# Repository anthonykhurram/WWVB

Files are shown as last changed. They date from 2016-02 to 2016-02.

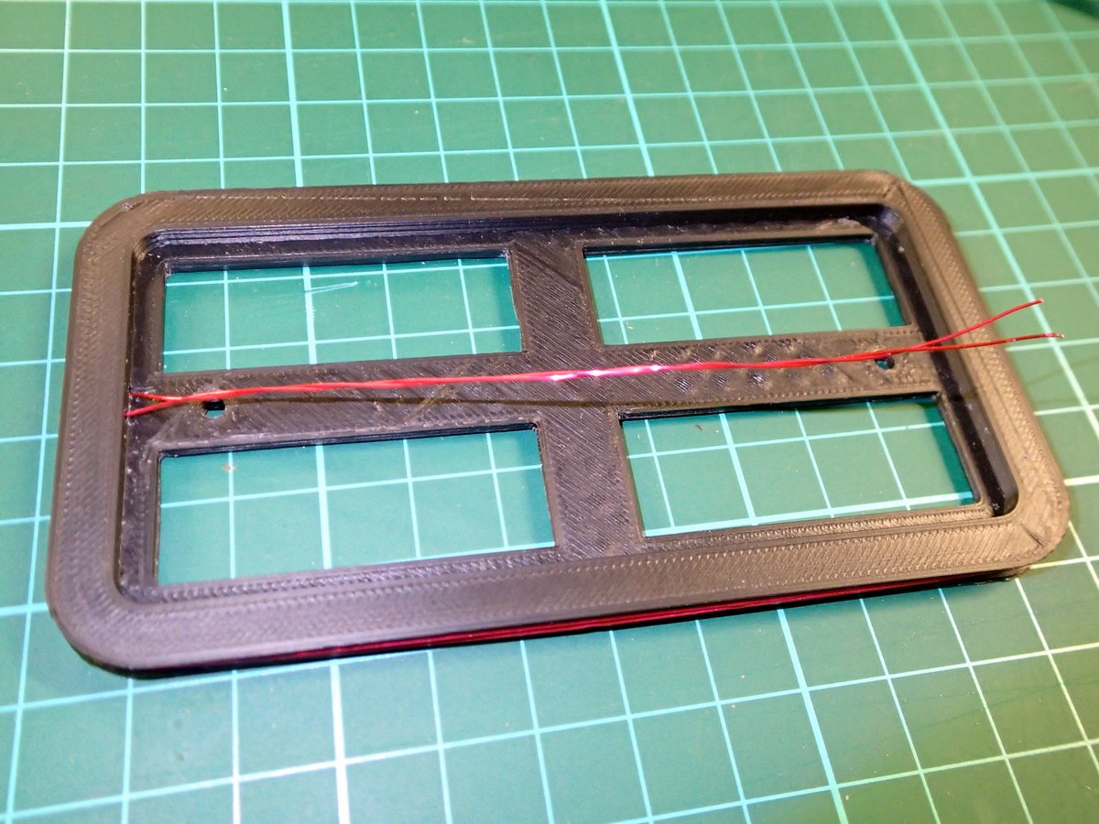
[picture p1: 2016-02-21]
Images & schematic/Coil1.JPG

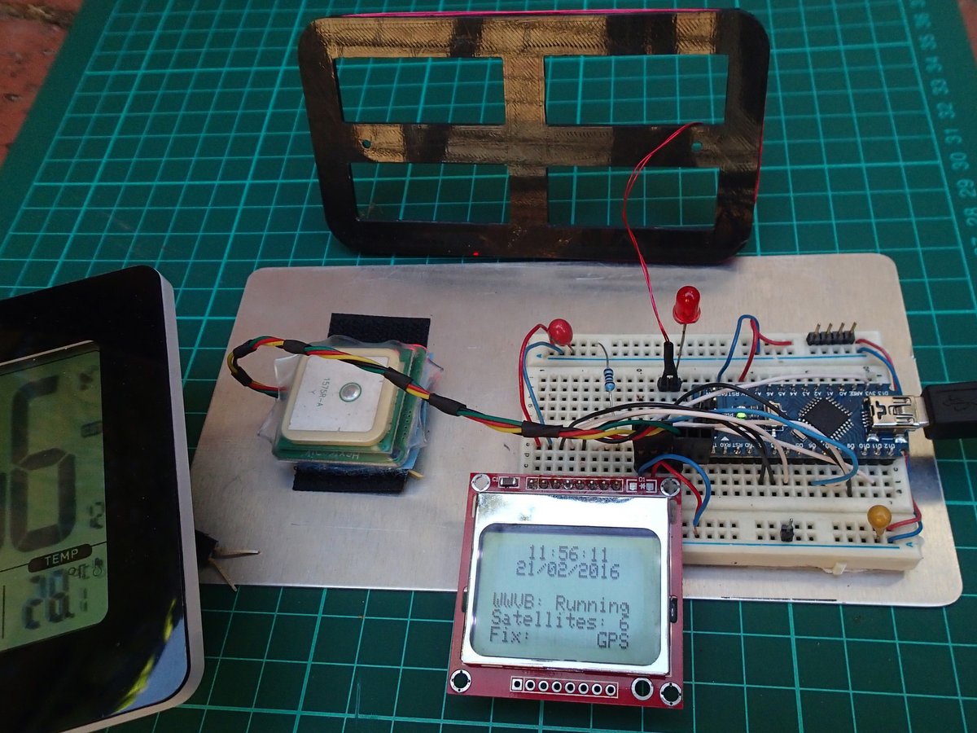
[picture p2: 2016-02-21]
Images & schematic/Breadboard1.JPG

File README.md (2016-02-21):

## Arduino Nano with Nokia LCD 60Khz WWVB Transmitter for setting radio controlled 'Atomic Clocks' like Oregon Scientific, Baldr, Casio Wave Ceptor, Citizen etc. 
An Arduino based WWVB transmitter project. The point of this is to get sub second time accuracy on radio controlled clocks in countries that don't support it.

## Tested successfully on a Baldr brand WWVB clock so far.
https://www.youtube.com/watch?v=lA-yf535rdY :Demo video of a radio controlled clock setting its time from the project.

## Not tested successfully on other devices as yet.

## Basic system info
The Nano uses the serial UTC time strings from the GPS module to synchronize a low power WWVB time signal transmission (range approx 1 meter).
The arduino code converts the UTC time to local time for the Nokia LCD, and also converts UTC to different offset for the WWVB generation.
The reason for that is the WWVB clock may not be built to be used in the time zone you are in (like Australia).
So a clock made for the USA, Japan or Europe can be set to display correct for any other time zone automatically (I have a Baldr desk clock made for the USA, and use it in Australia). 
The Nokia LCD shows current local time as read from the serial GPS module. The lower half of the LCD shows the WWVB and GPS statuses.
The WWVB time information will be output for 6 minutes before the Nano will re-sync with the GPS time and repeat. 
Radio Controlled clocks periodically try to receive a WWVB signal during the night and update the time. This project should enable clocks and watches within a meter or so to do this also.
The anticipated usage would be to have this on a bedside table and your radio controlled wrist watch and alarm clock will update each night to sub second accurate time (just like it would in countries like the USA, Japan, Europe, China).

Compile time options are:
GPS module type
Local time zone offset
WWVB time zone offset
Nokia LCD contrast value

* Author/s: [Mark Cooke](https://www.github.com/micooke), [Martin Sniedze](https://www.github.com/mr-sneezy)

## Requirements
* [TimeDateTools.h](https://github.com/micooke/ATtinyGPS/TimeDateTools.h)
* [ATtinyGPS.h](https://github.com/micooke/ATtinyGPS/ATtinyGPS.h) : for setting time based off a serial GPS
* [wwvb.h](https://github.com/micooke/WWVB/wwvb.h) : WWVB library
* Arduino Nano or clone
* Serial GPS module like a uBlox 6M or MTK 3329 that works with 5V supply.
* Nokia 5110 display module  - https://www.sparkfun.com/products/10168

##Options
* 3D printed coil bobbin (coil holder)  - http://www.thingiverse.com/thing:1358090

## About
http://www.nist.gov/pml/div688/grp40/wwvb.cfm

WWVB: 60kHz carrier, Amplitude modulated to Vp -17dB for signal low

## TODO:
* Draw up a schematic. If you can't wait it's actually fairly easy to use the pin diagram in the INO. 
* The GPS is direct connected to the Nano, the LCD also. Use a 1K to 500 ohm for the LCD back light limiting. The coil is driven directly through a limiting resistor or through an LED (the real current limiting is by the AVRs internal I/O limiter).
* Also to do, add LCD backlight control via the Nano. Use two digital pins via diodes and two resistors to have 'day & night' brightness settings, set by real time.

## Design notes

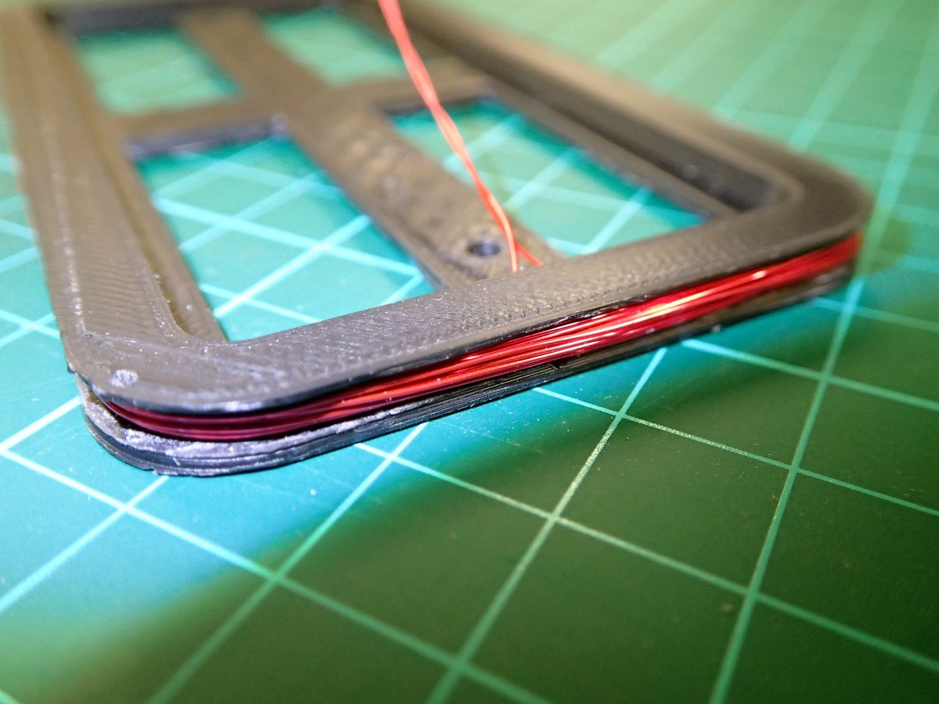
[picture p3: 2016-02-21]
Images & schematic/Coil2.JPG

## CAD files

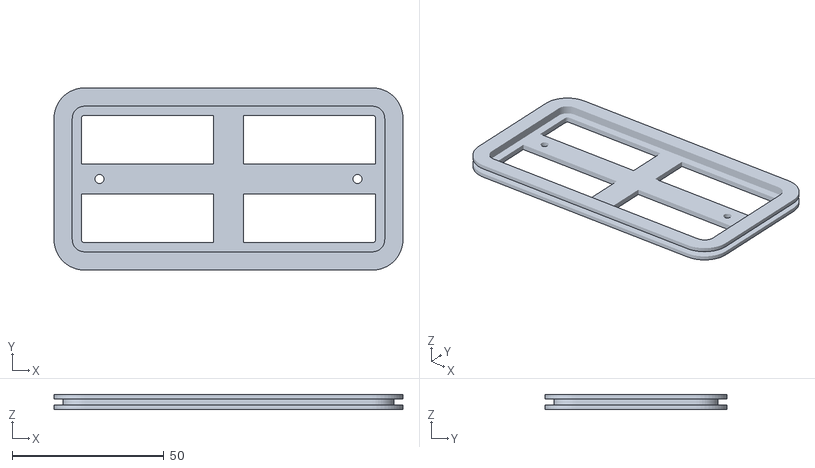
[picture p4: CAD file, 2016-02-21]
Images & schematic/WWVB Coil 1.stl
115.0 x 60.0 x 5.00

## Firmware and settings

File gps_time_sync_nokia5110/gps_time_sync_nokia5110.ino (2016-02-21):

#include <Arduino.h>
//ATtiny85 - Not enough pins & compile size too large
//
//Arduino Nano
//              +----+=====+----+
//              |    | USB |    |
// LCD CLK <= 13| D13+-----+D12 |12 MISO
//              |3V3        D11~|11 => LCD Din
//              |Vref       D10~|10 SS
//            14| A0/D14     D9~|9 => WWVB ANTENNA
//            15| A1/D15     D8 |8
//            16| A2/D16     D7 |7 <= GPS Tx (Software Serial)
//            17| A3/D17     D6~|6 => GPS Rx (Software Serial)
//        SDA 18| A4/D18     D5~|5
//        SCL 19| A5/D19     D4 |4 => LCD RST
//            20| A6         D3~|3 => LCD CE/CS (Chip Enable)
//            21| A7         D2 |2 => LCD DC (Data/Command Select)
//              | 5V        GND |
//              | RST       RST |
//              | GND       TX1 |0
//              | Vin       RX1 |1
//              |  5V MOSI GND  |
//              |   [ ][ ][ ]   |
//              |   [*][ ][ ]   |
//              | MISO SCK RST  |
//              +---------------+
//
//Arduino Micro
//              +--------+=====+---------+
//              |        | USB |         |
//        SCK 13| D13    +-----+     D12 |12 MISO
//              |3V3                 D11~|11 => LCD Din
//              |Vref                D10~|10 SS
// LCD DC  <= 14| A0/D14              D9~|9 => WWVB ANTENNA
// LCD CE  <= 15| A1/D15              D8 |8
// LCD RST <= 16| A2/D16              D7 |7 <= GPS Tx (Software Serial)
//            17| A3/D17              D6~|6 => GPS Rx (Software Serial)
//        SDA 18| A4/D18              D5~|5
//        SCL 19| A5/D19              D4 |4
//            20| A6                  D3~|3 INT1
//            21| A7                  D2 |2 INT0
//              | 5V                 GND |
//              | RST                RST |
//              | GND                TX1 |0
//              | Vin                RX1 |1
//              |MISO MISO[*][ ]VCC    SS|
//              |SCK   SCK[ ][ ]MOSI MOSI|
//              |      RST[ ][ ]GND      |
//              +------------------------+
//
//Sparkfun Pro Micro
//                             +----+=====+----+
//                             |[J1]| USB |    |
//                            1| TXO+-----+RAW |
//                            0| RXI       GND |
//                             | GND       RST |
//                             | GND       VCC |
//                        SDA 2| D2         A3 |21
//                        SCL 3|~D3         A2 |20 => LCD RST
//                            4| D4         A1 |19 => LCD CE
//                            5|~D5         A0 |18 => LCD DC
//GPS Tx (Software Serial) <= 6|~D6        D15 |15 => LCD CLK
//GPS Rx (Software Serial) => 7| D7        D14 |14 MISO
//                            8| D8        D16 |16 => LCD Din
//           WWVB ANTENNA  <= 9|~D9        D10~|10
//                             +---------------+

/*
Recommended debug setup
Use a RC (low-pass) filter to view the message (p1) as well as the modulated carrier (p0)

T = RC = 1/(2*pi*fc)
where;
T: Time constant
fc: cutoff frequency

for: R = 110 ohm, C = 1uF
fc = 1/(2*pi*RC) = 1.45kHz (the carrier is 60kHz, the modulation is about 1 to 5 Hz)

WWVB_OUT |--(p0)--[110R]--(p1)--[1uF]--|GND

-----------+-----------+-----------------
Chip       | #define   | WWVB_OUT
-----------+-----------+-----------------
ATtiny85   |  USE_OC1A | D1 / PB1 (pin 6)
ATtiny85   | *USE_OC1B | D4 / PB4 (pin 3)
-----------+-----------+-----------------
ATmega32u4 | *USE_OC1A | D9
ATmega32u4 |  USE_OC1B | D10
-----------+-----------+-----------------
ATmega328p | *USE_OC1A | D9
ATmega328p |  USE_OC1B | D10
-----------+-----------+-----------------

* Default setup
*/

//#define _DEBUG 1 // Serial output
#define _DEBUG 0

bool sync_gpstime = true;

uint32_t t0;

#include <TimeDateTools.h> // include before wwvb.h AND/OR ATtinyGPS.h
#include <wwvb.h> // include before ATtinyGPS.h
wwvb wwvb_tx;

// The ISR sets the PWM pulse width to correspond with the WWVB bit
ISR(TIMER1_OVF_vect)
{
	wwvb_tx.interrupt_routine();
}

#include <SoftwareSerial.h>
#if defined(__AVR_ATmega16U4__) | defined(__AVR_ATmega32U4__)
SoftwareSerial ttl(10, 6);// Rx, Tx pin
#else
SoftwareSerial ttl(7, 6);// Rx, Tx pin
#endif

#define GPS_MODULE 0 // ublox : Flash 16,812 bytes, SRAM 1299 bytes
//#define GPS_MODULE 1 // mediatek (default) : Flash 16,138 bytes, SRAM 1053 bytes

#include <ATtinyGPS.h>
ATtinyGPS gps;

#include <SPI.h>
#include <Adafruit_GFX.h>
#include <Adafruit_PCD8544.h>

#if defined(__AVR_ATmega16U4__) | defined(__AVR_ATmega32U4__)
Adafruit_PCD8544 nokia5110 = Adafruit_PCD8544(A0, A1, A2); // HardwareSPI
#else
Adafruit_PCD8544 nokia5110 = Adafruit_PCD8544(2, 3, 4); // HardwareSPI
#endif

const int8_t local_timezone[2] = {10, 30};
const int8_t wwvb_timezone[2] = {-6, 0};

void setup()
{
	wwvb_tx.setup();

	// Set the wwvb calibration values
	// ATmega328p : _DEBUG = 0 or 1 : frametime for calibrate( 86, 86) = 60.000254s
	// ATmega32u4 : _DEBUG = 0 or 1 : frametime for calibrate(-6,-6) = 59.999825s
	wwvb_tx.setPWM_LOW(0);
	wwvb_tx.calibrate(33,34); // 60.000017s
	// calibration
	//(0, 0) = 59.966523s (86, 86) = 60.052528s
	// 60.052528/(0.086005 / 86) = 52.5249 - so calibrate to (86,86) - (53,52) = (33,34)

	// set the timezone before you set your time
	gps.setTimezone(local_timezone[0], local_timezone[1]); // set this to your local time e.g. (ACDT = UTC +10:30)
	
	// if you are using CST (UTC -6:00), set the timezone to +6,0
	wwvb_tx.setTimezone(-wwvb_timezone[0], -wwvb_timezone[1]);
	
	ttl.begin(9600);

	gps.setup(ttl);

	nokia5110.begin();
	nokia5110.setContrast(50);
	nokia5110.setTextSize(1);
	nokia5110.setTextColor(BLACK);

	updateDisplay();
#if (_DEBUG > 0)
	Serial.begin(9600);
	Serial.println("Start");
#endif
}

void disableSoftwareSerialRead()
{
	// Note : SoftwareSerial enables all pin change interrupt registers
	// disable the pin change interrupt
#if defined(__AVR_ATtiny25__) | defined(__AVR_ATtiny45__) | defined(__AVR_ATtiny85__)
// GIMSK  = [   -   |  INT0 |  PCIE |   -   |   -   |   -   |   -   |   -   ]
//GIMSK = 0x00;
// PCMSK0 = [   -   |   -   | PCINT5| PCINT4| PCINT3| PCINT2| PCINT1| PCINT0]
//          [   -   |   -   |    RST|    PB4|    PB3|    PB2|    PB1|    PB0]
	PCMSK = 0x00;
#elif defined(__AVR_ATmega16U4__) | defined(__AVR_ATmega32U4__)
// PCICR  = [   -   |   -   |   -   |   -   |   -   |   -   |   -   |  PCIE0]
//PCICR = 0x00;
// PCMSK0 = [ PCINT7| PCINT6| PCINT5| PCINT4| PCINT3| PCINT2| PCINT1| PCINT0]
//          [    D12|    D11|    D10|     D9|   MISO|   MOSI|    SCK|     SS]
	PCMSK0 = 0x00;
#else
// PCICR  = [   -   |   -   |   -   |   -   |   -   |  PCIE2|  PCIE1|  PCIE0]
//PCICR = 0x00;
// PCMSK2 = [PCINT23|PCINT22|PCINT21|PCINT20|PCINT19|PCINT18|PCINT17|PCINT16]
//          [     D7|     D6|     D5|     D4|     D3|     D2|     D1|     D0]
	PCMSK2 = 0x00;
	// PCMSK1 = [   -   |PCINT14|PCINT13|PCINT12|PCINT11|PCINT10|PCINT09|PCINT08]
	//          [   -   |    RST|     A5|     A4|     A3|     A2|     A1|     A0]
	PCMSK1 = 0x00;
	// PCMSK0 = [ PCINT7| PCINT6| PCINT5| PCINT4| PCINT3| PCINT2| PCINT1| PCINT0]
	//          [  XTAL2|  XTAL1|    D13|    D11|    D12|    D10|     D9|     D8]
	PCMSK0 = 0x00;
#endif
}

void enableSoftwareSerialRead()
{
	// Note : SoftwareSerial enables all pin change interrupt registers
	// disable the pin change interrupt
#if defined(__AVR_ATtiny25__) | defined(__AVR_ATtiny45__) | defined(__AVR_ATtiny85__)
// GIMSK  = [   -   |  INT0 |  PCIE |   -   |   -   |   -   |   -   |   -   ]
// PCMSK0 = [   -   |   -   | PCINT5| PCINT4| PCINT3| PCINT2| PCINT1| PCINT0]
//          [   -   |   -   |    RST|    PB4|    PB3|    PB2|    PB1|    PB0]
	PCMSK |= _BV(PCINT2) | _BV(PCINT1);
#elif defined(__AVR_ATmega16U4__) | defined(__AVR_ATmega32U4__)
// PCICR  = [   -   |   -   |   -   |   -   |   -   |   -   |   -   |  PCIE0]
// PCMSK0 = [ PCINT7| PCINT6| PCINT5| PCINT4| PCINT3| PCINT2| PCINT1| PCINT0]
//          [    D12|    D11|    D10|     D9|   MISO|   MOSI|    SCK|     SS]
	PCMSK0 |= _BV(PCINT5); // enable pin interrupt on D10
#else
// PCICR  = [   -   |   -   |   -   |   -   |   -   |  PCIE2|  PCIE1|  PCIE0]
// PCMSK2 = [PCINT23|PCINT22|PCINT21|PCINT20|PCINT19|PCINT18|PCINT17|PCINT16]
//          [     D7|     D6|     D5|     D4|     D3|     D2|     D1|     D0]
	PCMSK2 |= _BV(PCINT23); // enable pin interrupt on D7
	// PCMSK1 = [   -   |PCINT14|PCINT13|PCINT12|PCINT11|PCINT10|PCINT09|PCINT08]
	//          [   -   |    RST|     A5|     A4|     A3|     A2|     A1|     A0]
	// PCMSK0 = [ PCINT7| PCINT6| PCINT5| PCINT4| PCINT3| PCINT2| PCINT1| PCINT0]
	//          [  XTAL2|  XTAL1|    D13|    D11|    D12|    D10|     D9|     D8]
#endif
}

// Set the default time to GPS epoch : UTC 00:00 on 06/Jan/1980
uint8_t ss = 0, mm = 0, hh = 0, DD = 6, MM = 1, YY = 80;

void updateDisplay()
{
	nokia5110.clearDisplay();
	nokia5110.setCursor(0, 0);
	if (sync_gpstime)
	{
		// increment the internal time while wwvb is stopped (as it is syncing with gps)
		addTimezone<uint8_t>(hh, mm, ss, DD, MM, YY, 0, 0, 1);
	}
	else
	{
		// get the time from the wwvb state
		hh = wwvb_tx.hh();
		mm = wwvb_tx.mm();
		ss = wwvb_tx.ss();
		DD = wwvb_tx.DD();
		MM = wwvb_tx.MM();
		YY = wwvb_tx.YY();
		
		// Convert wwvb time transmitted time to local time
		addTimezone<uint8_t>(hh, mm, ss, DD, MM, YY, wwvb_timezone[0], wwvb_timezone[1], 0);
	}
	// line 1
	//nokia5110.print("   HH:MM:SS   ");
	nokia5110.print("   ");
	if (hh < 10) { nokia5110.print(0); } // zero pad
	nokia5110.print(hh); nokia5110.print(":");
	if (mm < 10) { nokia5110.print(0); } // zero pad
	nokia5110.print(mm); nokia5110.print(":");
	if (ss < 10) { nokia5110.print(0); } // zero pad
	nokia5110.println(ss);
	// line 2
	//nokia5110.print("  DD/MM/YYYY  ");
	nokia5110.print("  ");
	if (DD < 10) { nokia5110.print(0); } // zero pad
	nokia5110.print(DD); nokia5110.print("/");
	if (MM < 10) { nokia5110.print(0); } // zero pad
	nokia5110.print(MM); nokia5110.print("/");
	if (YY < 80) { nokia5110.print(20); } // year pad ;)
	else { nokia5110.print(19); }
	if (YY < 10) { nokia5110.print(0); } // zero pad
	nokia5110.println(YY);
	// line 3
	nokia5110.println("");
	// line 4
	nokia5110.print("WWVB: ");
	if (wwvb_tx.is_active())
	{
		nokia5110.print("Running");
	}
	else if (sync_gpstime)
	{
		nokia5110.print("Syncing");
	}
	else
	{
		nokia5110.print("    Off");
	}
	// line 5
	nokia5110.print("Satellites:");
	if (gps.satellites < 10) { nokia5110.print(" "); }
	nokia5110.print(gps.satellites);
	// line 6
	nokia5110.print("Fix:");
	if (gps.quality == 0)
	{
		nokia5110.print("  Invalid");
	}
	else
	{
		switch (gps.quality)
		{
		case 1:
			nokia5110.print("      GPS"); break;
		case 2:
			nokia5110.print("     DGPS"); break;
		case 3:
			nokia5110.print("      PPS"); break;
		case 4:
			nokia5110.print("      RTK"); break;
		case 5:
			nokia5110.print("float RTK"); break;
		case 6:
			nokia5110.print("DEAD RECN"); break;
		case 7:
			nokia5110.print("   MANUAL"); break;
		case 8:
			nokia5110.print("SIMULATED"); break;
		}
	}
	nokia5110.display();
}

void loop()
{
	// if we are receiving gps data, parse it
	if (sync_gpstime)
	{
#if (_DEBUG > 0)
		Serial.println("Sync gps");
#endif
		t0 = millis(); // sync the internal arduino millis() to the wwvb sync time
		enableSoftwareSerialRead(); // enable SoftwareSerial pin change interrupts
		ttl.listen(); // reset buffer status
		gps.new_data(); // clear gps.new_data

		// wait until we get gps data
		while (!(((gps.IsValid) | (gps.YY < 80)) & ((gps.ss == 0) & gps.new_data())))
		{
			while (ttl.available())
			{
				gps.parse(ttl.read());
			}
			// update display every 1s
			if (millis() - t0 >= 1000)
			{
				t0 = millis();
				updateDisplay();
			}
		}

		// disable the pin change interrupts that SoftwareSerial uses to read data
		// as it interferes with the wwvb timing
		ttl.stopListening();
		disableSoftwareSerialRead(); // disable SoftwareSerial pin change interrupts

		// Yeah im ignoring the last parameter to set whether we are in daylight savings time
		wwvb_tx.set_time(gps.hh, gps.mm, gps.DD, gps.MM, gps.YY);
		wwvb_tx.start();
#if (_DEBUG > 0)
		Serial.println("Start wwvb");
#endif
		sync_gpstime = false;
		t0 = millis(); // sync the internal arduino millis() to the wwvb sync time
	}

	if (!sync_gpstime)
	{
		// Note
		// * wwvb time is synced and wwvb transmission is started when minutes = 0,10,20,30,40 or 50
		// * wwvb transmission is stopped when minutes = 9,19,29,39,49 or 59
		//
		// In other words, wwvb will transmit for 9 minutes, then turn off and sync for a minute
		//
		if ((wwvb_tx.mm() % 10 == 9) & wwvb_tx.is_active())
		{
#if (_DEBUG > 0)
			Serial.println("Stop wwvb");
#endif
			wwvb_tx.stop();
			sync_gpstime = true;
		}
	}

	// update display every 1s
	if (millis() - t0 >= 1000)
	{
		t0 = millis();
		updateDisplay();
	}
}

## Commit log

2016-02-21 Project files
    Added an STL file of the coil bobbin (coil holder).
    [WWVB Coil 1.stl]
2016-02-21 Project images
    Images of my sender coil and the prototype breadboard layout.
